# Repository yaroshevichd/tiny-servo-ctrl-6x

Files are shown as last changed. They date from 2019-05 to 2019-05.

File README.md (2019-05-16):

It's a try to make PWM controller on X channel using AVR MCU. MCU communication is I2C.

At local market ATtiny44A is cheapeast one, plus it have enough pins to drive 6 servos, communicate using TWI, and 3 pins to custimze address. So it's possible to drive up to (2^3 - 1) * 6 = 42 servo, which is more than enough for my requirements.

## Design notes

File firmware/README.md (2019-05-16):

How to control PWM in software mode
===================================

For given hardware (ATtiny44) the following hardware will be used:

* Timer0 - to generate PWM pulses with frequency equal to 50 Hz. Timer0 interrupts have lower
  priority than Timer1 and this is fine. It's possible to make this frequency configurable in
  the given range from 31 to 255 Hz (because timer will be driven with 1024 presale).
* Timer1 - to control PWM pulse length (from 500us to 2500us). It's possible to make this value
  configurable in range from 8us up to 32128us.
* USI - to communicate with main MCU. MCU will have static base address (0x40) with ability to
  specify subaddress in range from 0 to 6, which is results in ability to connect up to 7 such
  devices.

It supposed that the following algorithm will provide enough precision:

* Build array of PWM data which includes the following:
  * Timer1 ticks count relative to previous array record, so that sum of all ticks will produce
    desired pulse length.
  * Mask of servo need to be disabled.
* Array sorting order is based on sorted array of desired servos positions, which in turns, must
  be sorted in ascending order.
* Timer0 must be configured to generate interrupt with desired frequency (by default 50 Hz).
* Timer0 COMPA interrupt must do the following:
  * Setup pointer to point first element of array
  * Set Timer1 registers in accordance to data in first element of array
  * Wait for some time, in case of necessity, before set all channels to HIGH and running Timer1
* Timer1 COMPA interrupt must do the following (it must be done faster than 64cc):
  * Disable channels specified in data which pointer points to
  * Advance pointer to 1 element forward
  * If number of ticks equals to zero then stop Timer1
  * Set Timer1 registers to count up to data which pointer points to

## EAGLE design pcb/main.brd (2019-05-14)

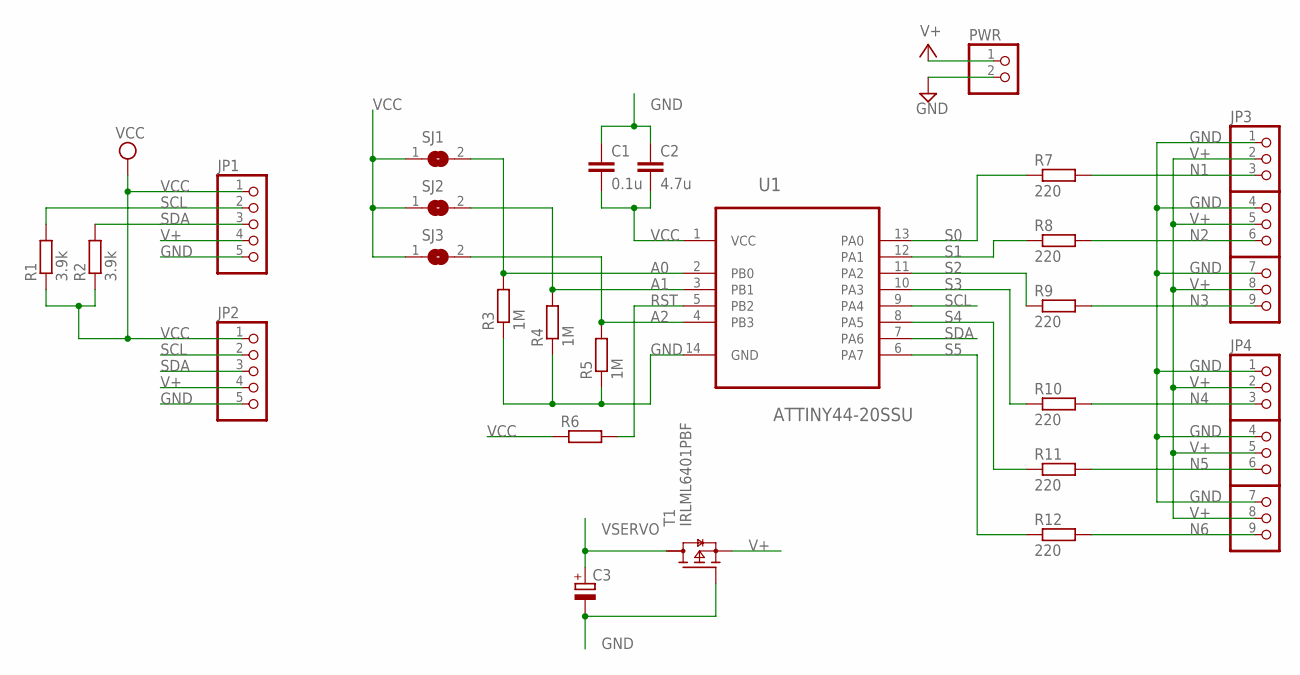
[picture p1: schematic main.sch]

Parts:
C1: 0.1u; C0805
C2: 4.7u; C0805
C3: CPOL-EUE2.5-6; E2,5-6
JP1, JP2: PINHD-1X5; 1X05
JP3, JP4: PINHD-3X3; 3X03
PWR: PINHD-1X2; 1X02
R1, R2: 3.9k; R0805
R3, R4, R5: 1M; R0805
R6: R-EU_R0805; R0805
R7, R8, R9, R10, R11, R12: 220; R0805
SJ1, SJ2, SJ3: SJ
T1: IRLML6401PBF; SOT23
U1: ATTINY44-20SSU; SOIC127P600X175-14N

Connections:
A0: R3.2, SJ1.2, U1.2 (PB0)
A1: R4.2, SJ2.2, U1.3 (PB1)
A2: R5.2, SJ3.2, U1.4 (PB3)
GND: C1.1, C2.1, C3.-, JP1.5, JP2.5, JP3.1, JP3.4, JP3.7, JP4.1, JP4.4, JP4.7, PWR.2, R3.1, R4.1, R5.1, T1.1 (G), U1.14 (GND)
N1: JP3.3, R7.2
N2: JP3.6, R8.2
N3: JP3.9, R9.2
N4: JP4.3, R10.2
N5: JP4.6, R11.2
N6: JP4.9, R12.2
RST: R6.2, U1.5 (PB2)
S0: R7.1, U1.13 (PA0)
S1: R8.1, U1.12 (PA1)
S2: R9.1, U1.11 (PA2)
S3: R10.1, U1.10 (PA3)
S4: R11.1, U1.8 (PA5)
S5: R12.1, U1.6 (PA7)
SCL: JP1.2, JP2.2, R1.2, U1.9 (PA4)
SDA: JP1.3, JP2.3, R2.2, U1.7 (PA6)
V+: JP1.4, JP2.4, JP3.2, JP3.5, JP3.8, JP4.2, JP4.5, JP4.8, PWR.1, T1.2 (S)
VCC: C1.2, C2.2, JP1.1, JP2.1, R1.1, R2.1, R6.1, SJ1.1, SJ2.1, SJ3.1, U1.1 (VCC)
VSERVO: C3.+, T1.3 (D)

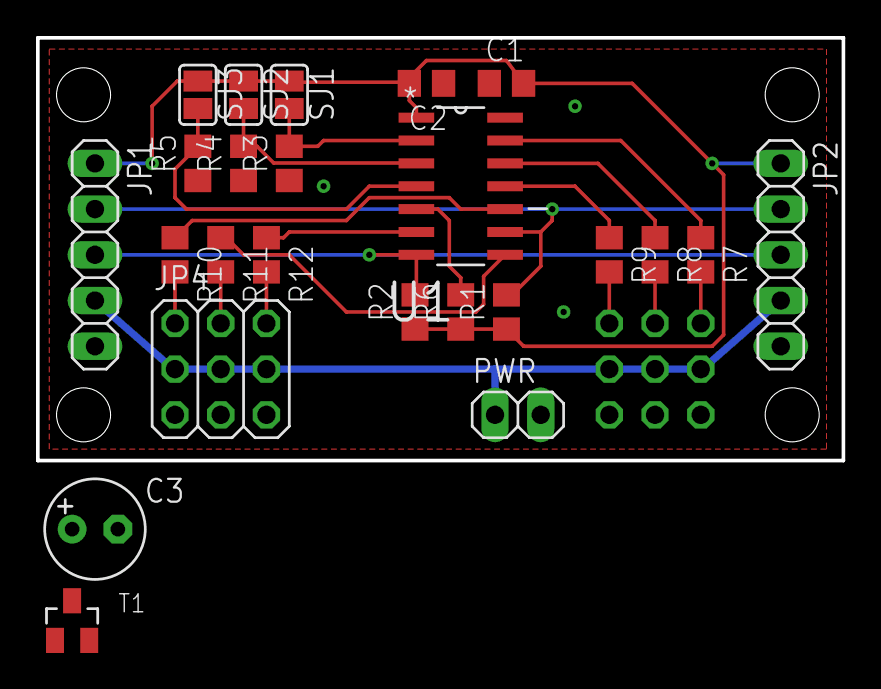
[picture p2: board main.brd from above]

Board: 2 copper layers, 44.8 x 23.5 mm, 25 parts (1 on the bottom side), 22 nets.

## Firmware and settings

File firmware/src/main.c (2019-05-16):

#include <string.h>
#include <avr/sleep.h>
#include <avr/interrupt.h>
#include <util/delay.h>
#include "avr_mcu_section.h"
#include "i2c.h"
#include "servo.h"
#include "twi.h"

#define MAIN_ADDRESS    (0x40)

#define NO_POSITION     (2^15 - 1)

#define MIN_FREQ_HZ     (32)        // each 256 timer ticks at 1024 div
#define MAX_FREQ_HZ     (255)       // each   1 timer tick at 1024 div

#define MIN_PULSE_10TH  (1)         // =0.001ms, or   1 timer tick  at 64 div
#define MAX_PULSE_10TH  (204)       // =2.040ms, or 256 timer ticks at 64 div


static uint8_t cur_register = 0;
static uint8_t registers[] =
{
    0,
    0, 0,
    0, 0,
    0, 0,
    0, 0,
    0, 0,
    0, 0,
};


const struct avr_mmcu_vcd_trace_t _AVR_MMCU_REGS[]  _MMCU_ = {
    { AVR_MCU_VCD_SYMBOL("SERVO0L"), .what = (void*)&registers[REG_SERVO0L], },
    { AVR_MCU_VCD_SYMBOL("SERVO0H"), .what = (void*)&registers[REG_SERVO0H], },
};

#define IS_TEST_MODE(x) (x & _BV(SFTM))
#define SET_TEST_MODE() { registers[REG_STATUS] |= _BV(SFTM); }
#define CLR_TEST_MODE() { registers[REG_STATUS] &= ~(_BV(SFTM)); }

#define IS_POS_DIRTY(x) (x & _BV(SFPD))
#define SET_DIRTY_POS() { registers[REG_STATUS] |= _BV(SFPD); }
#define CLR_DIRTY_POS() { registers[REG_STATUS] &= ~(_BV(SFPD)); }


void on_data_request()
{
    twi_drop_out_data();    // always send data from scratch
    while (cur_register < sizeof(registers))
    {
        twi_send_uint8(registers[cur_register++]);
    }
    cur_register = 0;
}

void on_data_received(uint8_t bytes)
{
    cur_register = twi_get_uint8();
    while (twi_has_in_data())
    {
        const uint8_t data = twi_get_uint8();
        if (cur_register == REG_STATUS)
        {
            registers[cur_register] = data;
            // if (IS_TEST_MODE(data))
            // {
            //     SET_TEST_MODE();
            // }
            // if (IS_POS_DIRTY(data))
            // {
            //     SET_DIRTY_POS();
            // }
        }
        else if (cur_register >= REG_SERVO0L)
        {
            registers[cur_register] = data;
        }
        cur_register++;
    }
    cur_register = 0;
}

void update_positions()
{
    static servos_pos_t copy;
    memcpy(copy, &registers[REG_SERVO0L], sizeof(servos_pos_t));
    servo_set_many(copy);
}


int main()
{
    PRR |= _BV(PRADC);
    ACSR |= _BV(ACD);

    uint8_t subaddress = 0;
    // asm(
    //     "in     %[subaddr], %[port]\n\t"
    //     "sbrc   %[subaddr], %[pin3]\n\t"
    //     "sbr    %[subaddr], %[pin2m]\n\t"
    //     "cbr    %[subaddr], %[pin3m]\n\t"
    //     : [subaddr] "=&r" (subaddress)
    //     : [port] "I" (_SFR_IO_ADDR(PINB)),
    //       [pin3] "M" (PINB3),
    //       [pin3m] "M" (_BV(PINB3)),
    //       [pin2m] "M" (_BV(PINB2))
    // );

    servo_init(50, 200);
    twi_init(MAIN_ADDRESS + subaddress, on_data_request, on_data_received);
    servo_start();

    SET_TEST_MODE();

    sei();

    while (1)
    {
        if (!IS_TEST_MODE(registers[REG_STATUS]))
        {
            if (IS_POS_DIRTY(registers[REG_STATUS]))
            {
                update_positions();
                CLR_DIRTY_POS();
            }
            set_sleep_mode(SLEEP_MODE_IDLE);
            sleep_mode();
            continue;
        }

        static uint8_t count_up = 1;
        static servo_pos_t test_pos = MIN_POS_DEG;

        servo_pos_t *ptr_reg = (servo_pos_t*)&(registers[REG_SERVO0L]);
        for (uint8_t i = 0; i < SERVOS_COUNT; ++i, ++ptr_reg)
        {
            *ptr_reg = test_pos;
        }
        update_positions();
        int16_t adj = count_up ? +5 : -5;

        if (test_pos + adj >= MAX_POS_DEG)
        {
            count_up = 0;
            test_pos = MAX_POS_DEG;
        }
        else if (test_pos + adj <= MIN_POS_DEG)
        {
            count_up = 1;
            test_pos = MIN_POS_DEG;
        }
        else
        {
            test_pos += adj;
        }

        _delay_ms(35);
    };

    return 0;
}

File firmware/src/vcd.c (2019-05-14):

#include <avr/io.h>
#include "avr_mcu_section.h"

AVR_MCU(F_CPU, "attiny44");
AVR_MCU_VCD_FILE("tiny_servo_6x.vcd", 1);

const struct avr_mmcu_vcd_trace_t _AVR_MMCU_SERVO[]  _MMCU_ = {
    { AVR_MCU_VCD_SYMBOL("SERVO-0"), .mask = _BV(PA0), .what = (void*)&PORTA, },
    { AVR_MCU_VCD_SYMBOL("SERVO-1"), .mask = _BV(PA1), .what = (void*)&PORTA, },
    { AVR_MCU_VCD_SYMBOL("SERVO-2"), .mask = _BV(PA2), .what = (void*)&PORTA, },
    { AVR_MCU_VCD_SYMBOL("SERVO-3"), .mask = _BV(PA3), .what = (void*)&PORTA, },
    { AVR_MCU_VCD_SYMBOL("SERVO-4"), .mask = _BV(PA5), .what = (void*)&PORTA, },
    { AVR_MCU_VCD_SYMBOL("SERVO-5"), .mask = _BV(PA7), .what = (void*)&PORTA, },
    { AVR_MCU_VCD_SYMBOL("OCR1A"), .what = (void*)&OCR1A, },
    { AVR_MCU_VCD_SYMBOL("TCCR0B"), .what = (void*)&TCCR0B, },
    { AVR_MCU_VCD_SYMBOL("TCNT1L"), .what = (void*)&TCNT1L, },
    { AVR_MCU_VCD_SYMBOL("TCCR1B"), .what = (void*)&TCCR1B, },
};

AVR_MCU_VCD_IRQ_TRACE(6, 1, "TIM1_COMPA");
AVR_MCU_VCD_IRQ_TRACE(9, 1, "TIM0_COMPA");

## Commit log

2019-05-14 PCB Design added
    [main.brd, main.sch]
2019-05-16 * Fix "unsigned int" overflow while calculate pulse length * Drop TWI transmit buffer before send new response
    [main.c]
2019-05-16 Update firmware README to reflect current implementation
